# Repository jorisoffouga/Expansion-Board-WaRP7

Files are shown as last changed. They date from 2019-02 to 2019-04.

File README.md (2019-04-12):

# Expansion-Board-WaRP7
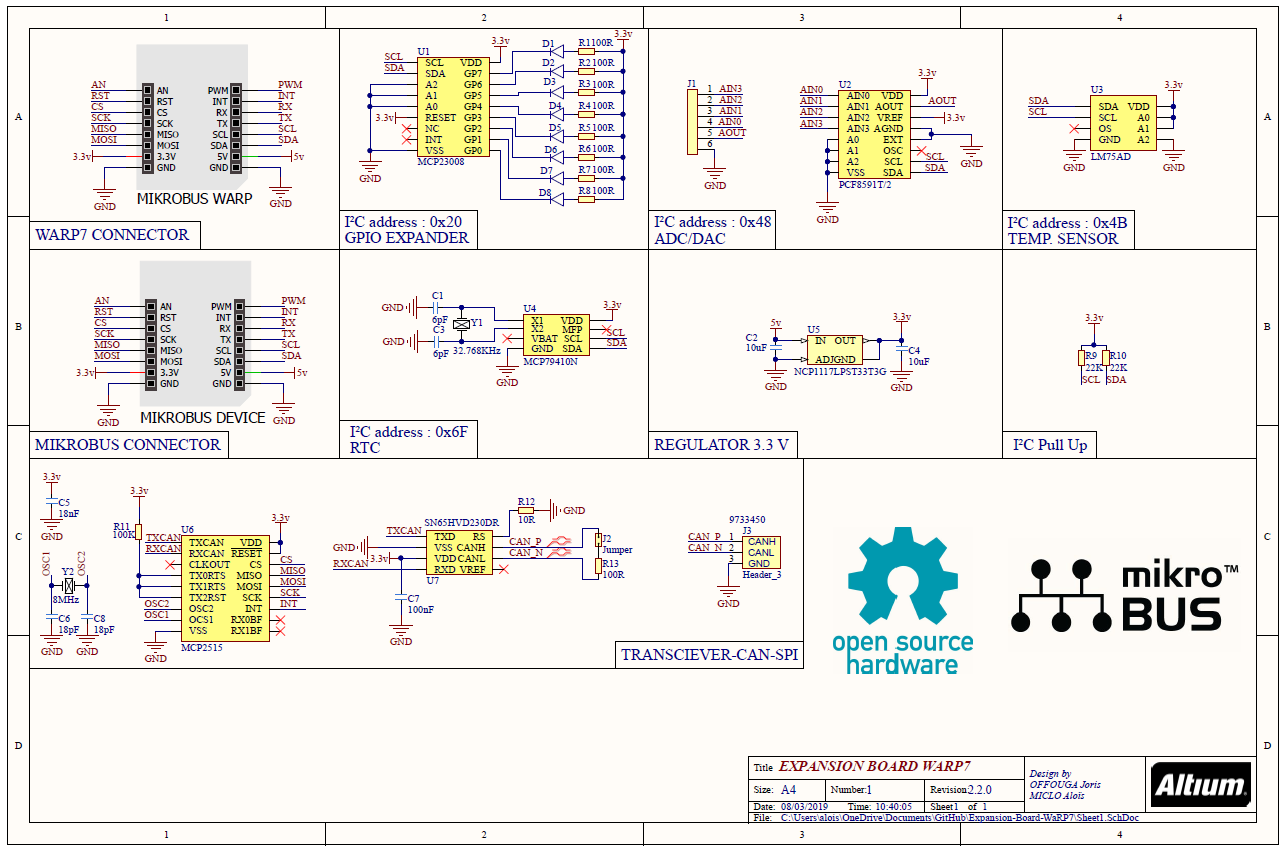
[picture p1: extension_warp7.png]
board


Developpement Board for WaRP7 : 

Temp sensor : [LM75AD](http://www.farnell.com/datasheets/693899.pdf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)

RTC : [MCP7940N](http://www.farnell.com/datasheets/2129560.pdf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) 

ADC/DAC : [PCF8591](http://www.farnell.com/datasheets/1759207.pdf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)

GPIO Expander : [MCP23S08](http://www.farnell.com/datasheets/12174.pdf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) 

Transceiver CAN-SPI : [MCP2515](http://www.farnell.com/datasheets/1669372.pdf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)

[Socket Mikrobus](https://www.mikroe.com/mikrobus)

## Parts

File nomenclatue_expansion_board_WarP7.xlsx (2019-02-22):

Colonne1 | Nom du produit | Nom du fabricant | Référence du fabricant | Nom du fournisseur | Référence du fournisseur | Quantité | Prenom etudiant | Etat de la commande | Prix unitaire H.T. (€) | Total H.T (€) | Prix TTC (€) | Commentaire | Total TTC
 | Regulator 3.3V | ON SEMICONDUCTOR | NCP1117LPST33T3G | Farnell | 2534283 | 1 |  |  | 0.407 | 0.407 | 0.49 |  | 27.77 €
 | BUS Can-SPI | MICROCHIP | MCP2515-E/SO | Farnell | 1605565 | 1 |  |  | 2.09 | 2.09 | 2.51
 | Temperature sensor | NXP | LM75AD,112 | Farnell | 1854077 | 1 |  |  | 0.436 | 0.436 | 0.52
 | GPIO Expander | MICROCHIP | MCP2008T-E/SO | Farnell | 2851556 | 1 |  |  | 0.964 | 0.964 | 1.16
 | ADC/DAC | NXP | PCF8591T/2,518 | Farnell | 2400442 | 1 |  |  | 2.92 | 2.92 | 3.50
 | RTC | MICROCHIP | MCP7040-I/SN | Farnell | 2361122 | 1 |  |  | 0.745 | 0.745 | 0.89
 | Transceiver CAN | MICROCHIP | MCP255-E/SN | Farnell | 1467746 | 1 |  |  | 1.18 | 1.18 | 1.42
 | Quart 8 MHz | IDQ FREQUENCY PRODUCT | LFXTAL056567 | Farnell | 2832065RL | 1 |  |  | 1.06 | 1.06 | 1.27
 | Quart 32.768 Khz | ABRACON | ABS07-1-20-32.768KHZ-T | Farnell | 2467864 | 1 |  |  | 0.566 | 0.566 | 0.68
 | Resistance 22K |  |  | Farnell | 2447607 | 2 |  |  | 0.0095 | 0.019 | 0.02
 | Resistance 10 R |  |  | Farnell | 2447556 | 1 |  |  | 0.0097 | 0.0097 | 0.01
 | Resistance 100 K |  |  | Farnell | 1469860 | 1 |  |  | 0.0344 | 0.0344 | 0.04
 | Resistance 100 R |  |  | Farnell | 1738946 | 9 |  |  | 0.0879 | 0.7911 | 0.95
 | Condensateur 6pF |  |  | Farnell | 1759185 | 2 |  |  | 0.0583 | 0.1166 | 0.14
 | Condensateur 18pF |  |  | Farnell | 1759194 | 2 |  |  | 0.0648 | 0.1296 | 0.16
 | Condensateur 18nF |  |  | Farnell | 1759251 | 1 |  |  | 0.0792 | 0.0792 | 0.10
 | Condensateur 100nF |  |  | Farnell | 2522443 | 1 |  |  | 0.0505 | 0.0505 | 0.06
 | Condensateur 10uF |  |  | Farnell | 9402144 | 2 |  |  | 0.205 | 0.41 | 0.49
 | Header 2 pins |  |  | Farnell | 9733302 | 1 |  |  | 0.407 | 0.407 | 0.49
 | Header 3 pins |  |  | Farnell | 9733450 | 1 |  |  | 0.565 | 0.565 | 0.68
 | Header 8 pins femelle |  |  | Farnell | 1593463 | 2 |  |  | 0.39 | 0.78 | 0.94
 | Header 8 pins |  |  | Farnell | 9733345 | 2 |  |  | 1.09 | 2.18 | 2.62
 | Header 6 pins |  |  | Farnell | 2751311 | 1 |  |  | 0.222 | 0.222 | 0.27
 | LED Bleu vert |  |  | Farnell | 2614990 | 8 |  |  | 0.872 | 6.976 | 8.37

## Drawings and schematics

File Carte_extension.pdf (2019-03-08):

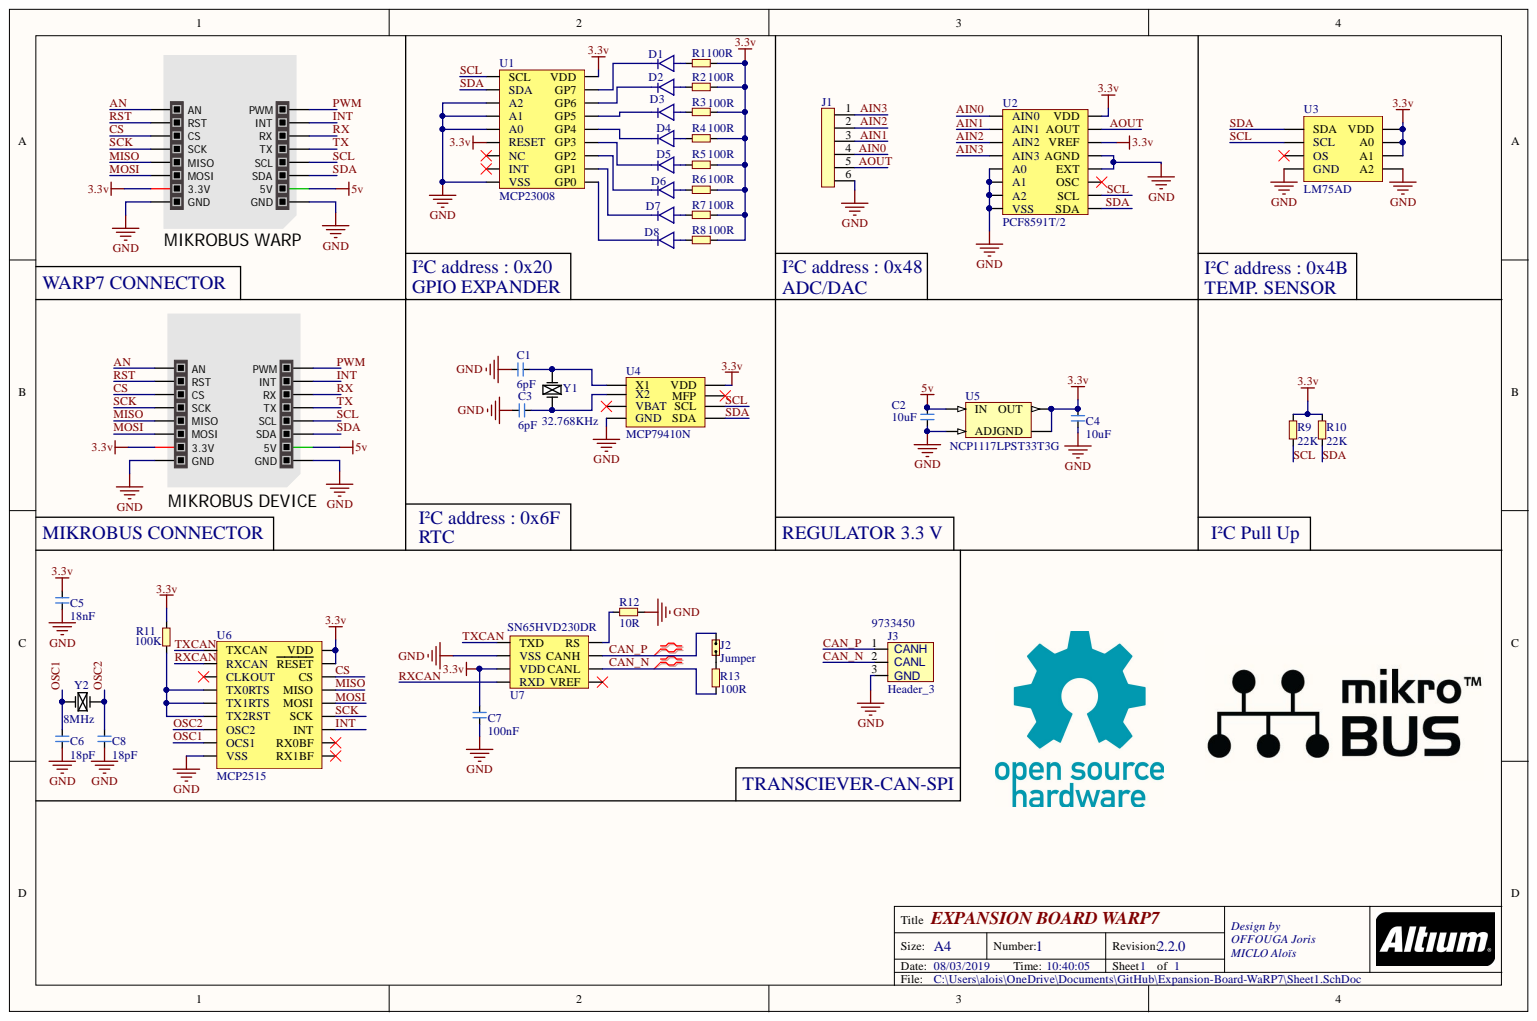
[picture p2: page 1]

EXPANSION BOARD WARP7 Title | Design by OFFOUGA Joris MICLO Aloïs

Size: A4 | Number: 1 | Revision: 2.2.0
Date: 08/03/2019 Time: 10:40:05 | | Sheet 1 of 1

C:\Users\alois\OneDrive\Documents\GitHub\Expansion-Board-WaRP7\Sheet1.SchDoc

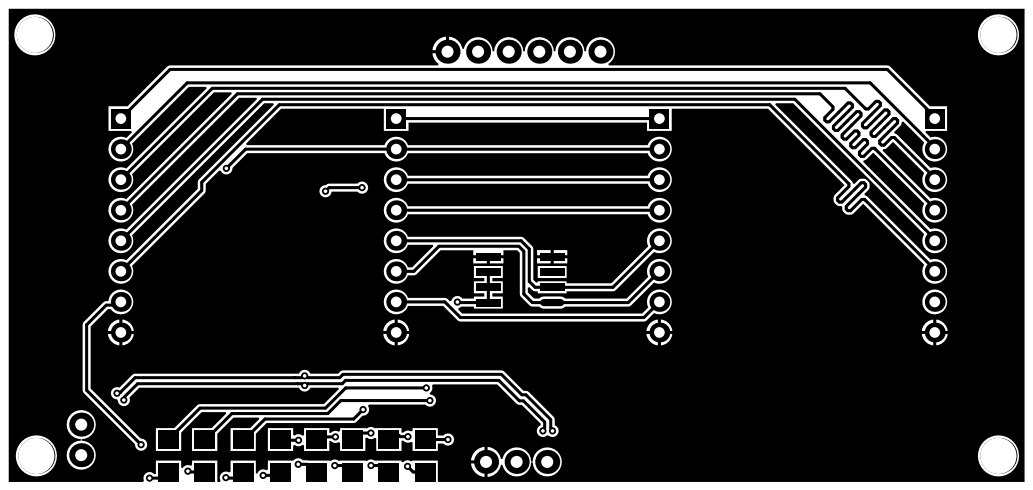
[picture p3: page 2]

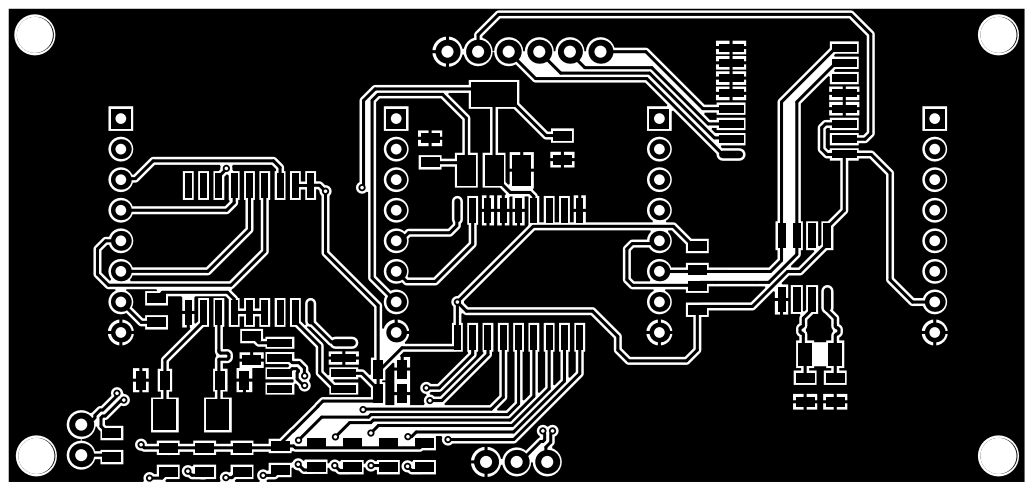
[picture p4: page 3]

# Board Stack Report

Stack Up | Layer Stack
Layer | Board Layer Stack | Name | Material | Thickness | Constant

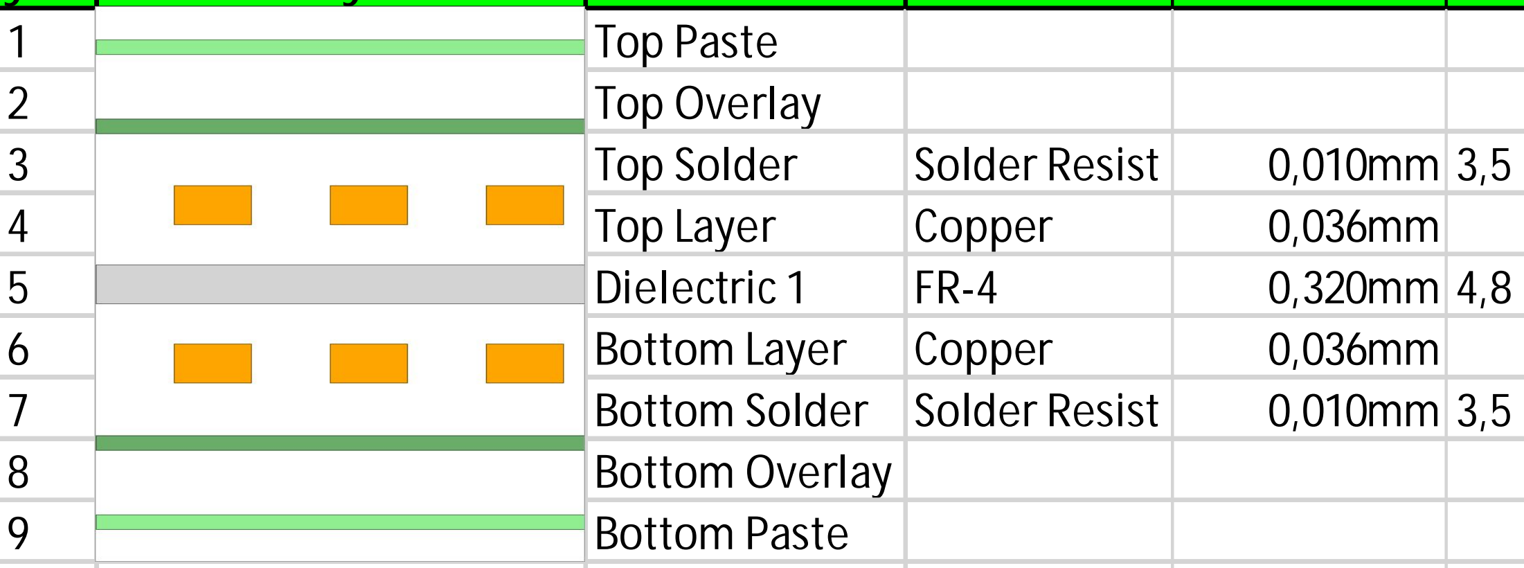
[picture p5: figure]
Top Paste; Top Overlay; Top Solder; Solder Resist; Top Layer; Copper; Dielectric 1; Bottom Layer; Bottom Overlay; Bottom Paste

7 | | Bottom Solder | Solder Resist | 0,010mm | 3,5
| Height : 0,411mm

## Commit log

2019-02-22 Design review
    Design review & schematic review
    [Carte_extension.PrjPcb, PCB1.PcbDoc, PcbLib1.PcbLib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]
2019-02-22 review
    schematic review, add supplier references
    [Sheet1.SchDoc, nomenclatue_expansion_board_WarP7.xlsx]
2019-02-27 Add Length tuning
    Add SPI length tuning and CAN differential pairs routing
    [PCB1.PcbDoc, Sheet1.SchDoc, mikroBUS_socket_standard.PcbLib]
2019-02-28 PCB Modification
    Modification of 8MHz Quartz footprint
    [PCB1.PcbDoc, PcbLib1.PcbLib, Sheet1.SchDoc]
2019-02-28 Modif
    Pull-up reset pin on GPIO Expender
    [PCB1.PcbDoc, Sheet1.SchDoc]
2019-02-28 modif
    Add pull up on RST pin (GPIO expender)
2019-03-01 Modif
    SPI CAN Transceiver, reset pin state change
    [PCB1.PcbDoc, Schlib1.SchLib, Sheet1.SchDoc]
2019-03-08 Change component
    CAN tranciever reference change
    [PCB1.PcbDoc, Schlib1.SchLib, Sheet1.SchDoc]
2019-03-08 Add Board Stack Report
    [PCB1.PcbDoc]
